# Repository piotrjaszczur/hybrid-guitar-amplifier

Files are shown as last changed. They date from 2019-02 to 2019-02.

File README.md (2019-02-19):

# hybrid-guitar-amplifier
Hybrid guitar amplifier project for the Design Laboratory course at AGH

This amplifier consists of valve preamplifier and solid state power amplifier.

Equalizer
The schematic for the equalizer was taken from the AVT186 kit. The values of the components were changed to provide three bands for the filters: 100Hz, 800Hz and 6400Hz.

eq board

eq schematic

MOSFET overdive effect
It was simple two stage amplifier to create distorted signal with a harsh clipping.

mos board

mos schematic

Channel select board
This board allowed to change the channels of the preamplifier and control the effects loop with 3 analog multiplexers. They were handled by the Atmega328p microcontroller. 

mux board

mux schematic

Power amplifier
The TDA7292 was used in the bridge tied load configuration to increase the power output in this stage.

poweramp board

poweramp schematic

Valve preamplifier
This circuit was based around 12AX7 valve. The double triode provided two gain stages in order to achieve overdriven signal.

preamp board

preamp schematic

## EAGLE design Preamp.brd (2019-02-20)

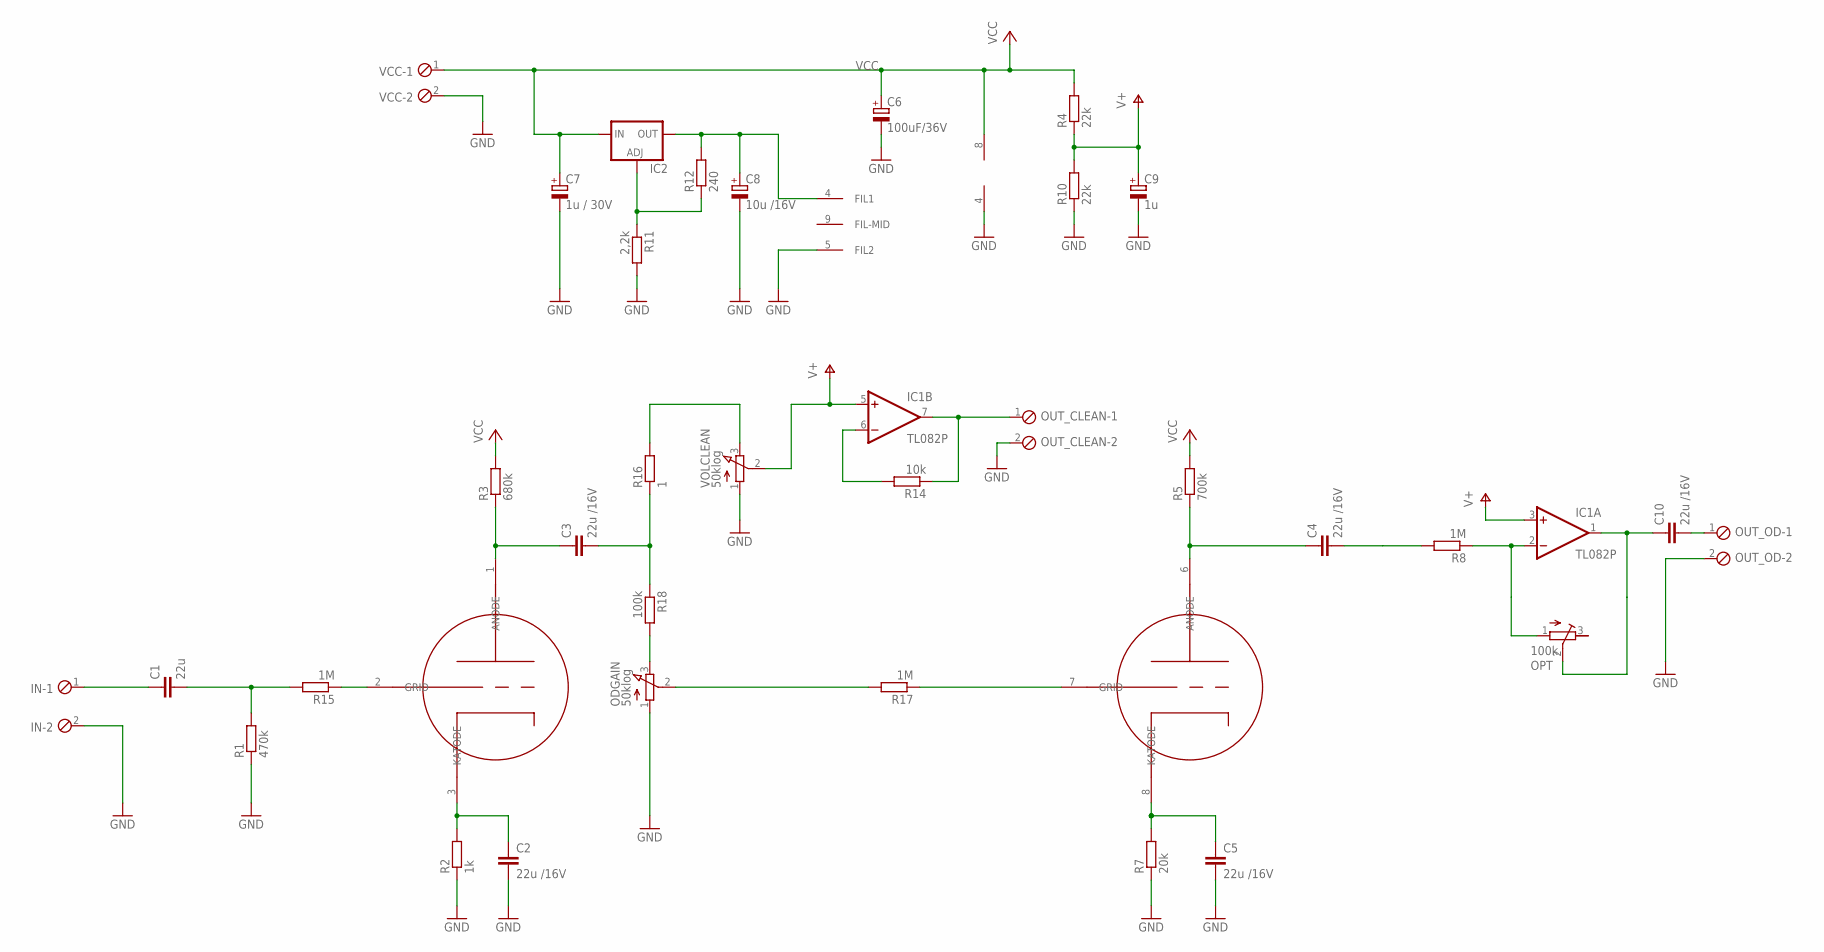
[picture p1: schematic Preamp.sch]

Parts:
C1: 22u; C050-030X075
C2, C3, C4, C5, C10: 22u /16V; C050-030X075
C6: 100uF/36V; E2,5-5
C7: 1u / 30V; E2,5-5
C8: 10u /16V; E2,5-5
C9: 1u; E2,5-5
IC1: TL082P; DIL08
IC2: LM317TS; 317TS
IN: MPT2; 2POL254
ODGAIN: 50klog; 3RP/1610N
OPT: 100k; RTRIM74W
OUT_CLEAN: MPT2; 2POL254
OUT_OD: MPT2; 2POL254
R1: 470k; 0207/12
R2: 1k; 0207/12
R3: 680k; 0207/12
R4, R10: 22k; 0207/12
R5: 700k; 0207/12
R7: 20k; 0207/10
R8, R15, R17: 1M; 0207/12
R11: 2,2k; 0207/12
R12: 240; 0207/12
R14: 10k; 0204/7
R16: 1; 0207/12
R18: 100k; 0207/12
U$1: 12AX7
VCC: MPT2; 2POL254
VOLCLEAN: 50klog; 3RP/1610N

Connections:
GND: C2.2, C5.2, C6.-, C7.-, C8.-, C9.-, IC1.4 (V-), IN.2, ODGAIN.1 (A), OUT_CLEAN.2, OUT_OD.2, R1.1, R2.1, R7.1, R10.1, R11.2, U$1.5 (FIL2), VCC.2, VOLCLEAN.1 (A)
unnamed: C1.2, R1.2, R15.2
unnamed: C2.1, R2.2, U$1.3 (KATODE)
unnamed: C5.1, R7.2, U$1.8 (KATODE)
unnamed: C3.1, R3.1, U$1.1 (ANODE)
unnamed: C3.2, R16.1, R18.1
unnamed: C4.1, R5.1, U$1.6 (ANODE)
unnamed: C4.2, R8.2
unnamed: C1.1, IN.1
unnamed: IC1.2 (-IN), OPT.1 (A), R8.1
unnamed: ODGAIN.2 (S), R17.2
unnamed: C10.1, IC1.1 (OUT), OPT.2 (S)
unnamed: IC1.7 (OUT), OUT_CLEAN.1, R14.1
unnamed: C8.+, IC2.2 (OUT), R12.2, U$1.4 (FIL1)
unnamed: R15.1, U$1.2 (GRID)
unnamed: IC2.1 (ADJ), R11.1, R12.1
unnamed: IC1.6 (-IN), R14.2
unnamed: R17.1, U$1.7 (GRID)
unnamed: R16.2, VOLCLEAN.3 (E)
unnamed: ODGAIN.3 (E), R18.2
unnamed: C10.2, OUT_OD.1
V+: C9.+, IC1.3 (+IN), IC1.5 (+IN), R4.1, R10.2, VOLCLEAN.2 (S)
VCC: C6.+, C7.+, IC1.8 (V+), IC2.3 (IN), R3.2, R4.2, R5.2, VCC.1

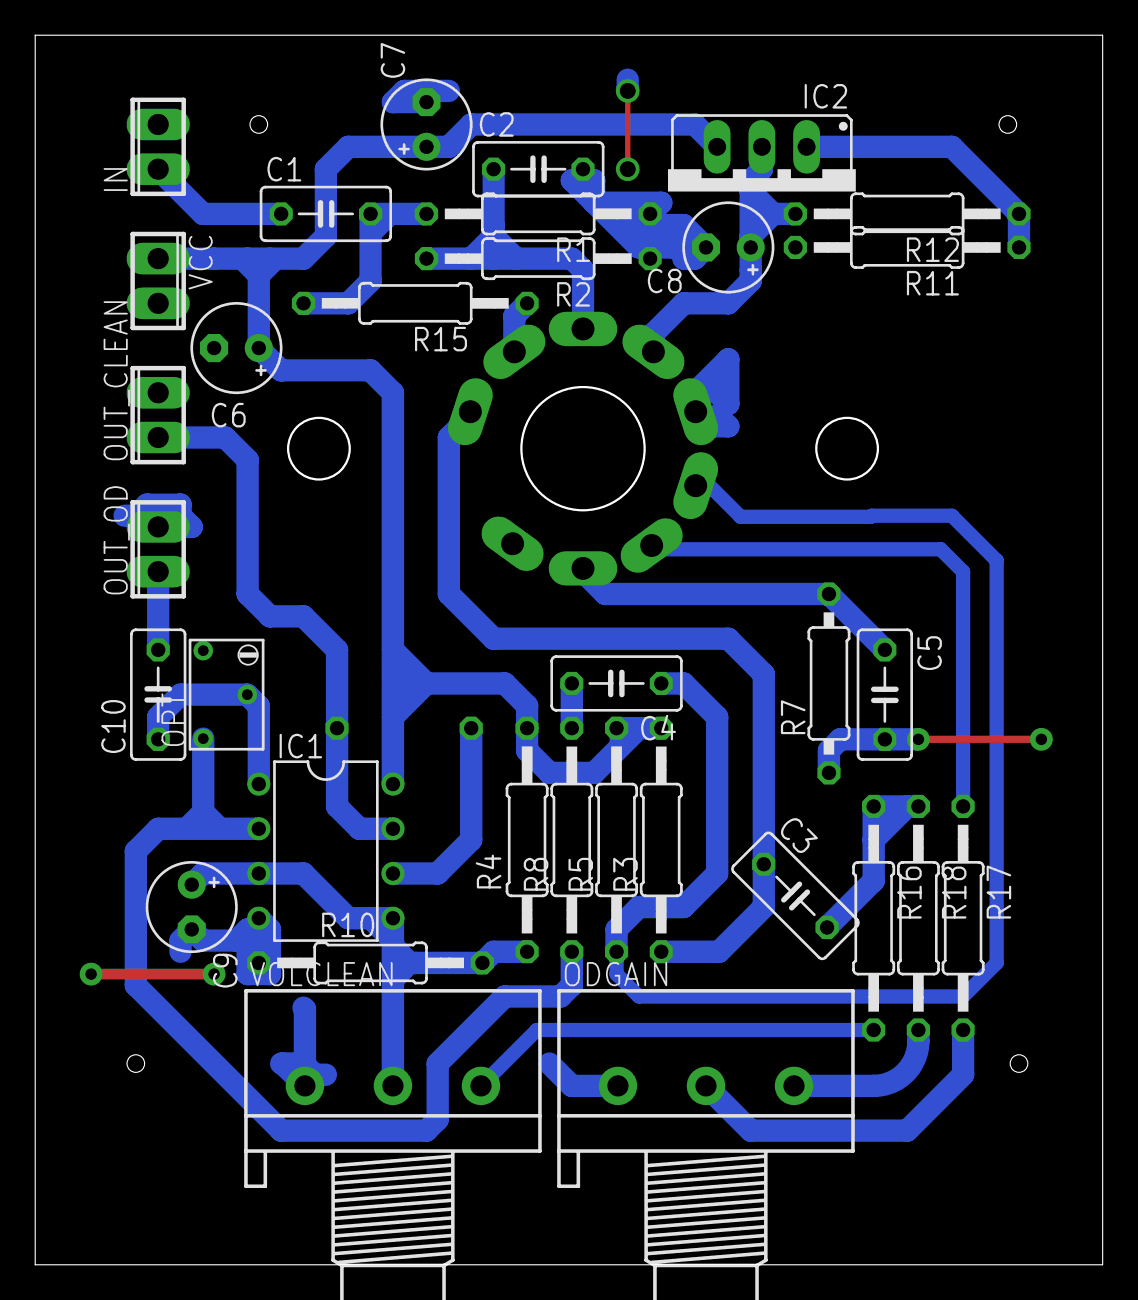
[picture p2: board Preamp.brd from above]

Board: 2 copper layers, 60.6 x 69.8 mm, 35 parts (1 on the bottom side), 23 nets.

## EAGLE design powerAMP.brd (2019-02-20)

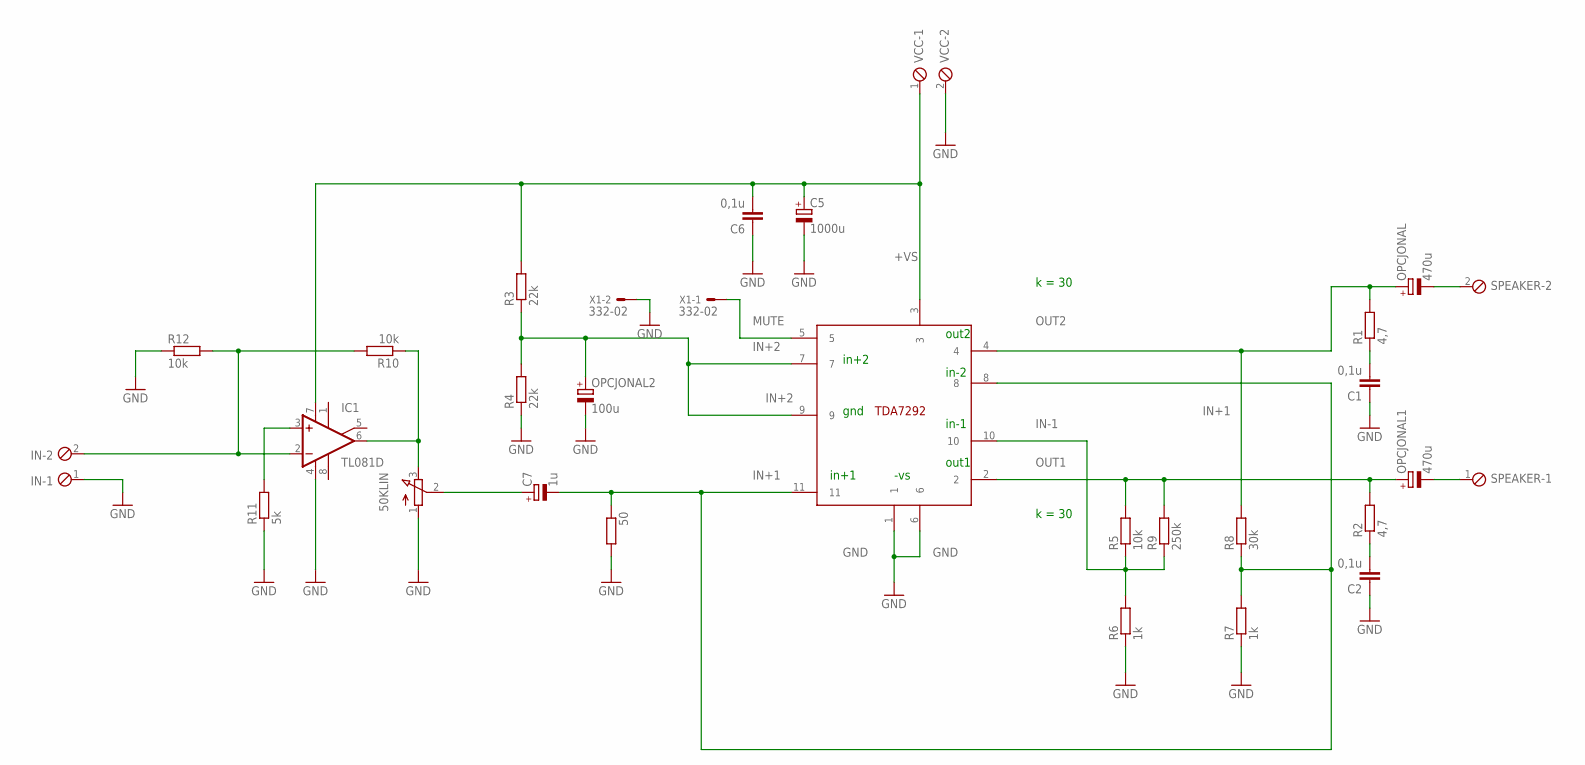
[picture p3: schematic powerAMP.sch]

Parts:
50: R-EU_M0805; M0805
50KLIN: 3RP/1610N
C1, C2, C6: 0,1u; C1206
C5: 1000u; E2,5-7
C7: 1u; E2,5-5
IC1: TL081D; SO08
IN: MPT2; 2POL254
OPCJONAL, OPCJONAL1: 470u; E2,5-7
OPCJONAL2: 100u; E2,5-7
R1, R2: 4,7; M0805
R3, R4: 22k; M0805
R5, R10, R12: 10k; M0805
R6, R7: 1k; M0805
R8: 30k; M0805
R9: 250k; M0805
R11: 5k; M0805
SPEAKER: MPT2; 2POL254
U$1: TDA7292TDA7292; MULTIWATT11
VCC: MPT2; 2POL254
X1: 332-02

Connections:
+VS: C5.+, C6.2, IC1.7 (V+), R3.2, U$1.3, VCC.1
GND: 50.2, 50KLIN.1 (A), C1.1, C2.1, C5.-, C6.1, IC1.4 (V-), IN.1, OPCJONAL2.-, R4.1, R6.1, R7.1, R11.1, R12.1, U$1.1, U$1.6, VCC.2, X1.2
IN+1: 50.1, C7.-, R7.2, R8.1, U$1.8, U$1.11
IN+2: OPCJONAL2.+, R3.1, R4.2, U$1.7, U$1.9
IN-1: R5.1, R6.2, R9.1, U$1.10
MUTE: U$1.5, X1.1
unnamed: C1.2, R1.1
unnamed: 50KLIN.3 (E), IC1.6 (OUT), R10.1
unnamed: 50KLIN.2 (S), C7.+
unnamed: C2.2, R2.1
unnamed: IC1.2 (-IN), IN.2, R10.2, R12.2
unnamed: IC1.3 (+IN), R11.2
OUT1: OPCJONAL1.+, R2.2, R5.2, R9.2, U$1.2
OUT2: OPCJONAL.+, R1.2, R8.2, U$1.4
SPK+: OPCJONAL1.-, SPEAKER.1
SPK-: OPCJONAL.-, SPEAKER.2

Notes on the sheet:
in-1
in+2
in-2
in+1
gnd
-vs
out1
out2
k = 30

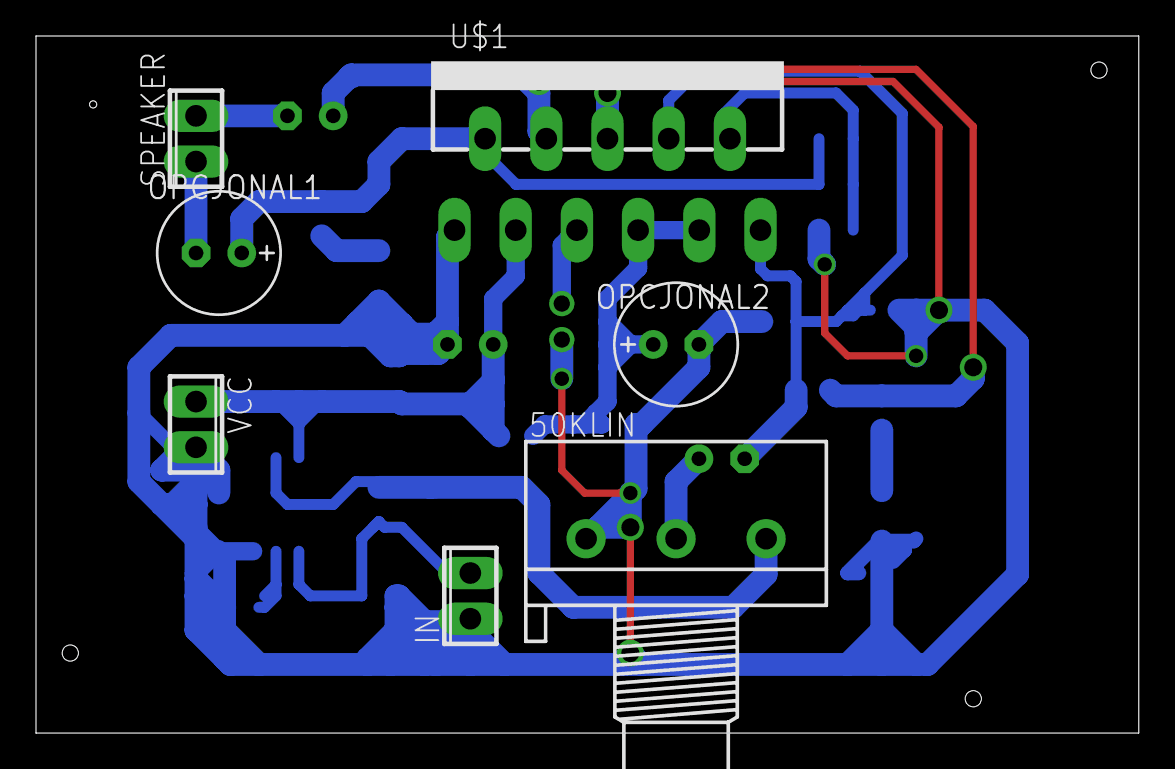
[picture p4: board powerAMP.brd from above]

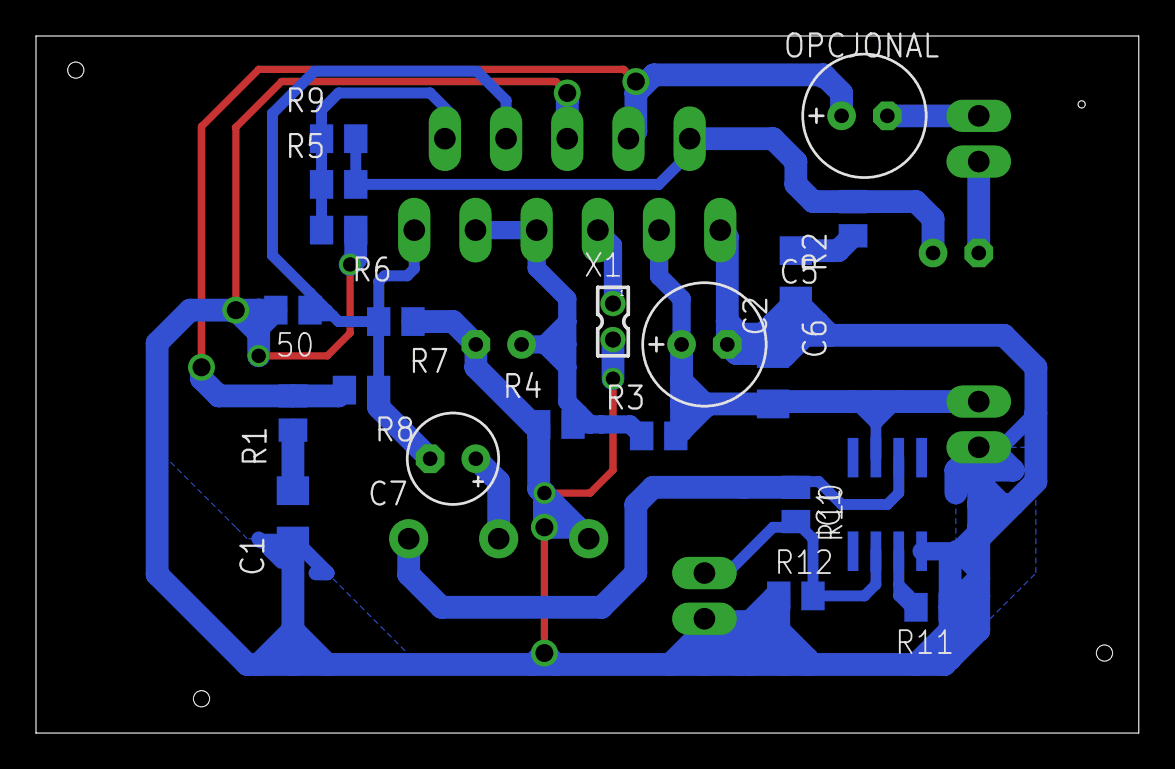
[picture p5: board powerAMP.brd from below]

Board: 2 copper layers, 61.3 x 38.7 mm, 28 parts (21 on the bottom side), 16 nets.

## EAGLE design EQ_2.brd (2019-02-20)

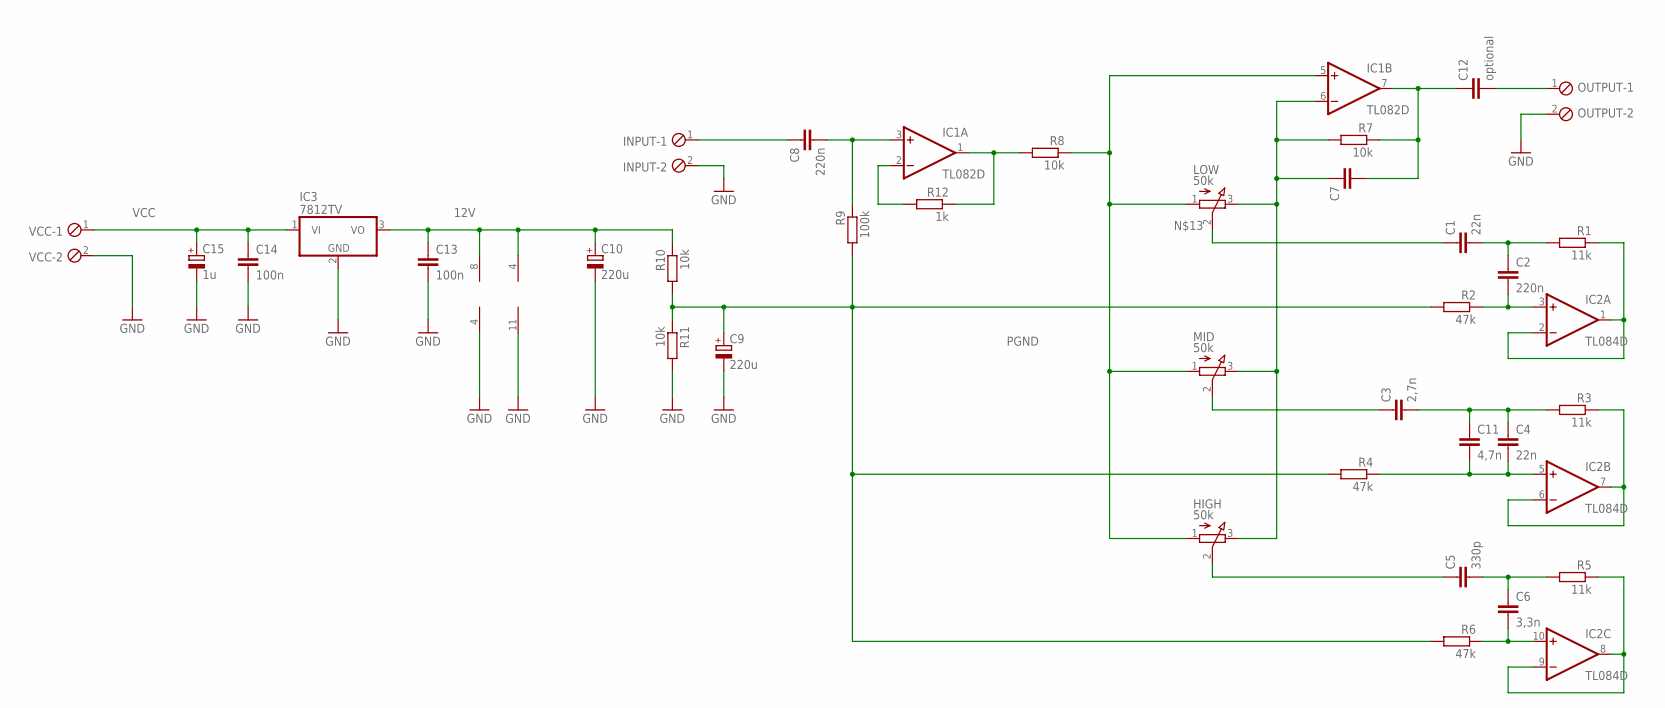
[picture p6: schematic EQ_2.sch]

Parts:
C1, C4: 22n; C1206
C2, C8: 220n; C1206
C3: 2,7n; C1206
C5: 330p; C1206
C6: 3,3n; C1206
C7: C-EUC1206; C1206
C9, C10: 220u; E2,5-5
C11: 4,7n; C1206
C12: optional; C1206
C13, C14: 100n; C1206
C15: 1u; E2,5-5
HIGH: 50k; 3RP/1610N
IC1: TL082D; SO08
IC2: TL084D; SO14
IC3: 7812TV; TO220V
INPUT: MPT2; 2POL254
LOW: 50k; 3RP/1610N
MID: 50k; 3RP/1610N
OUTPUT: MPT2; 2POL254
R1, R3, R5: 11k; R0805
R2, R4, R6: 47k; R0805
R7, R8, R10, R11: 10k; R0805
R9: 100k; R0805
R12: 1k; R0805
VCC: MPT2; 2POL254

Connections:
12V: C10.+, C13.1, IC1.8 (V+), IC2.4 (V+), IC3.3 (VO), R10.1
GND: C9.-, C10.-, C13.2, C14.2, C15.-, IC1.4 (V-), IC2.11 (V-), IC3.2 (GND), INPUT.2, OUTPUT.2, R11.2, VCC.2
unnamed: C2.2, IC2.3 (+IN), R2.1
unnamed: C1.2, C2.1, R1.2
unnamed: IC2.1 (OUT), IC2.2 (-IN), R1.1
unnamed: C3.2, C4.1, C11.1, R3.2
unnamed: C4.2, C11.2, IC2.5 (+IN), R4.1
unnamed: IC2.6 (-IN), IC2.7 (OUT), R3.1
unnamed: C5.2, C6.1, R5.2
unnamed: C6.2, IC2.10 (+IN), R6.1
unnamed: IC2.8 (OUT), IC2.9 (-IN), R5.1
unnamed: C7.2, C12.1, IC1.7 (OUT), R7.1
unnamed: C8.2, IC1.3 (+IN), R9.1
unnamed: C7.1, HIGH.3 (E), IC1.6 (-IN), LOW.3 (E), MID.3 (E), R7.2
unnamed: HIGH.1 (A), IC1.5 (+IN), LOW.1 (A), MID.1 (A), R8.1
unnamed: IC1.1 (OUT), R8.2, R12.1
unnamed: IC1.2 (-IN), R12.2
unnamed: C8.1, INPUT.1
unnamed: C5.1, HIGH.2 (S)
unnamed: C3.1, MID.2 (S)
unnamed: C1.1, LOW.2 (S)
unnamed: C12.2, OUTPUT.1
PGND: C9.+, R2.2, R4.2, R6.2, R9.2, R10.2, R11.1
VCC: C14.1, C15.+, IC3.1 (VI), VCC.1

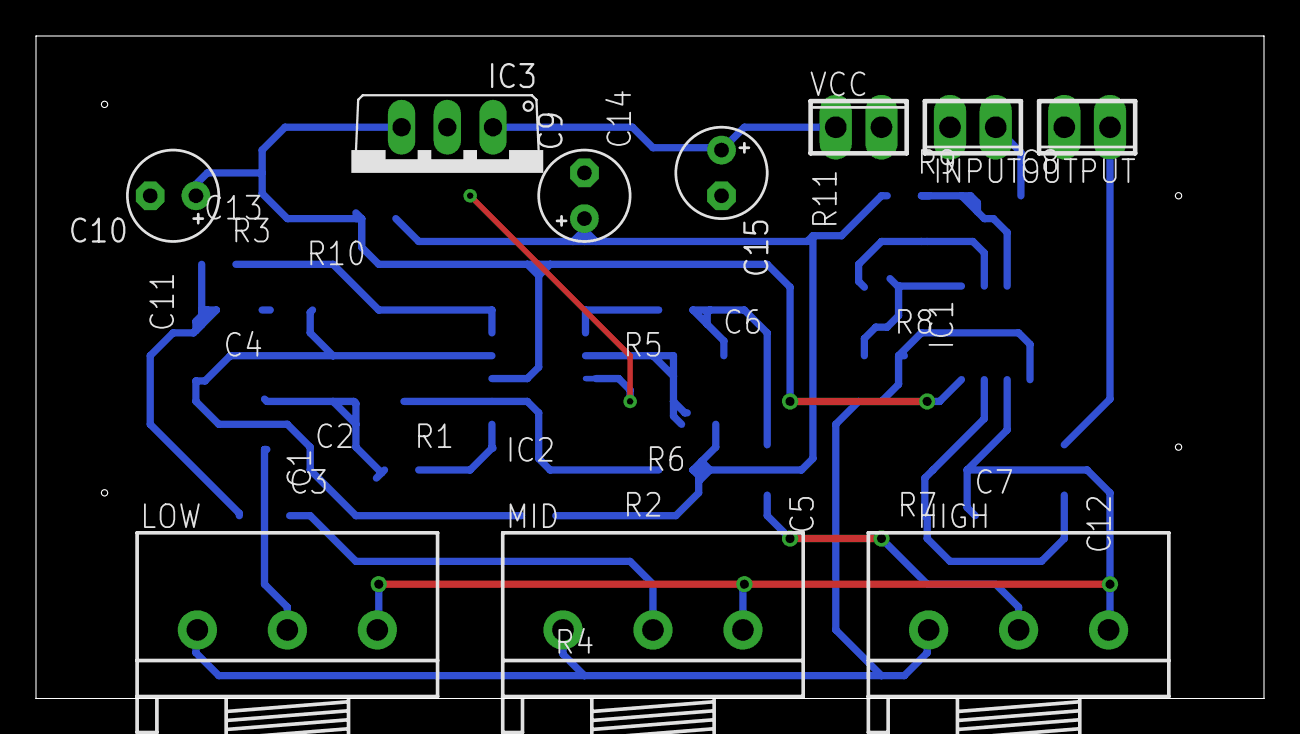
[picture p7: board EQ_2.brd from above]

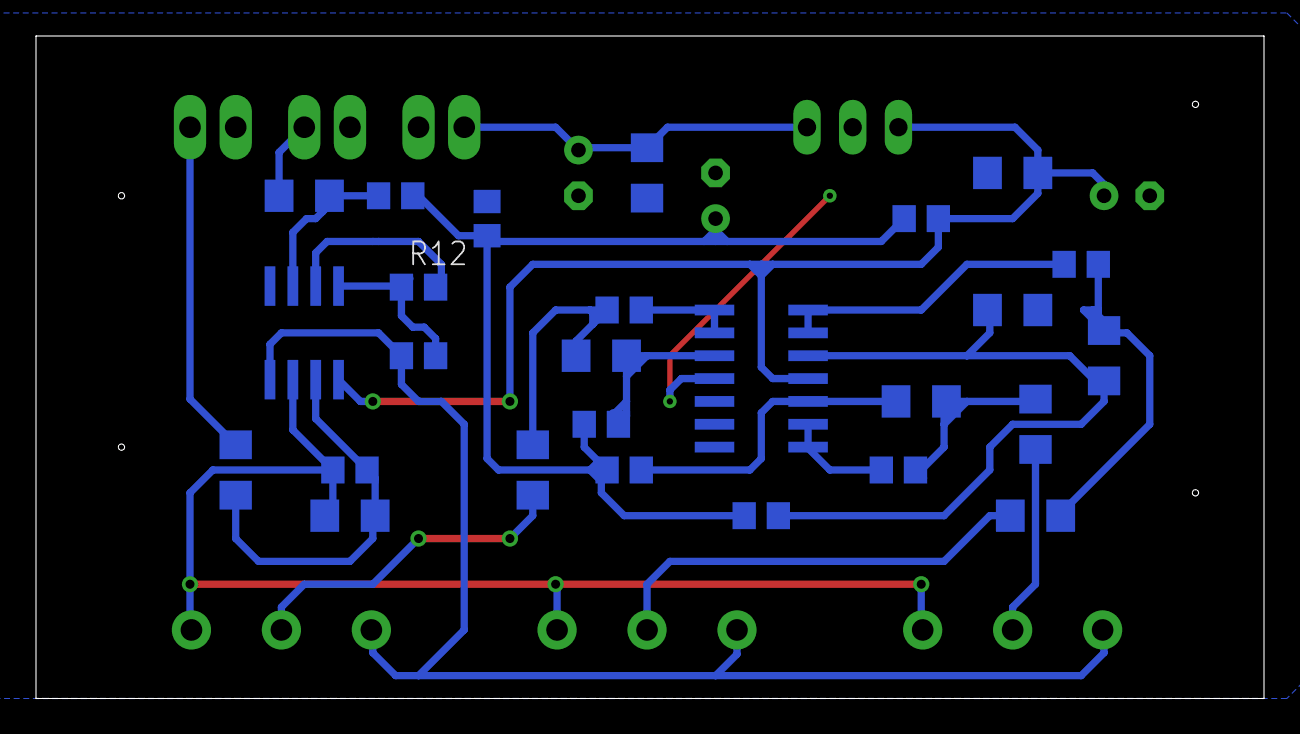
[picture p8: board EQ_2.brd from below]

Board: 2 copper layers, 68.2 x 36.8 mm, 36 parts (26 on the bottom side), 24 nets.

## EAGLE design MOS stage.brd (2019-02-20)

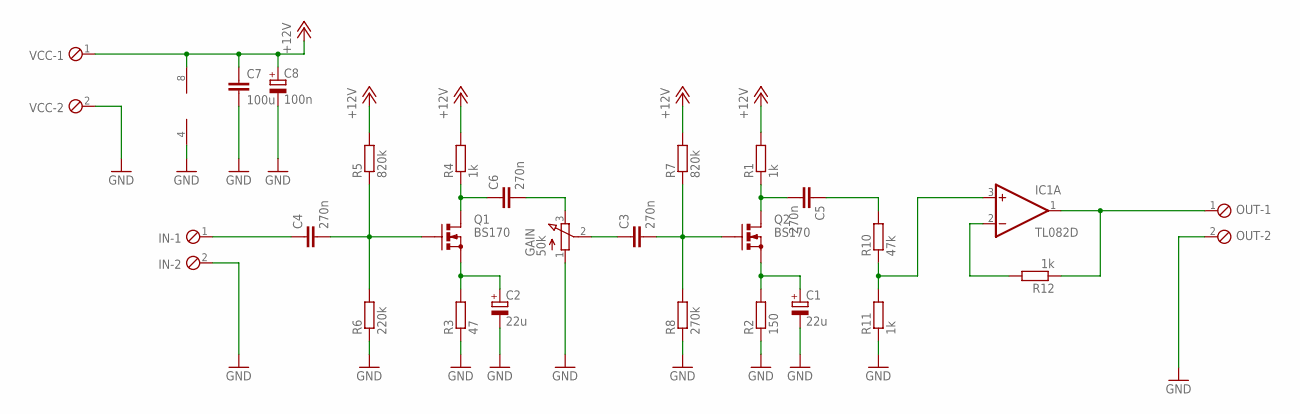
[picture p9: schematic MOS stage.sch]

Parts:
C1, C2: 22u; E2,5-5
C3, C4, C5, C6: 270n; C1206
C7: 100u; C1206
C8: 100n; E2,5-5
GAIN: 50k; 3RP/1610N
IC1: TL082D; SO08
IN: MPT2; 2POL254
OUT: MPT2; 2POL254
Q1, Q2: BS170; SOT54E
R1, R4, R11, R12: 1k; R0805
R2: 150; R0805
R3: 47; R0805
R5, R7: 820k; R0805
R6: 220k; R0805
R8: 270k; R0805
R10: 47k; R0805
VCC: MPT2; 2POL254

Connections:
+12V: C7.1, C8.+, IC1.8 (V+), R1.2, R4.2, R5.2, R7.2, VCC.1
GND: C1.-, C2.-, C7.2, C8.-, GAIN.1 (A), IC1.4 (V-), IN.2, OUT.2, R2.1, R3.1, R6.1, R8.1, R11.1, VCC.2
unnamed: C5.2, Q2.D, R1.1
unnamed: C3.2, Q2.G, R7.1, R8.2
unnamed: C1.+, Q2.S, R2.2
unnamed: C6.1, Q1.D, R4.1
unnamed: C2.+, Q1.S, R3.2
unnamed: C4.2, Q1.G, R5.1, R6.2
unnamed: C4.1, IN.1
unnamed: C5.1, R10.2
unnamed: C6.2, GAIN.3 (E)
unnamed: C3.1, GAIN.2 (S)
unnamed: IC1.3 (+IN), R10.1, R11.2
unnamed: IC1.1 (OUT), OUT.1, R12.1
unnamed: IC1.2 (-IN), R12.2

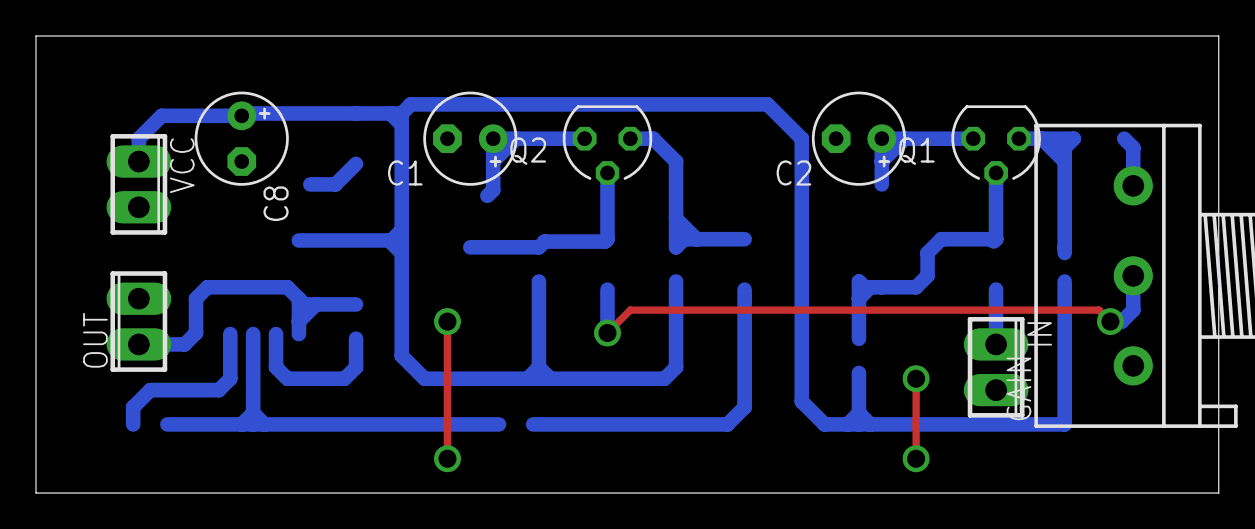
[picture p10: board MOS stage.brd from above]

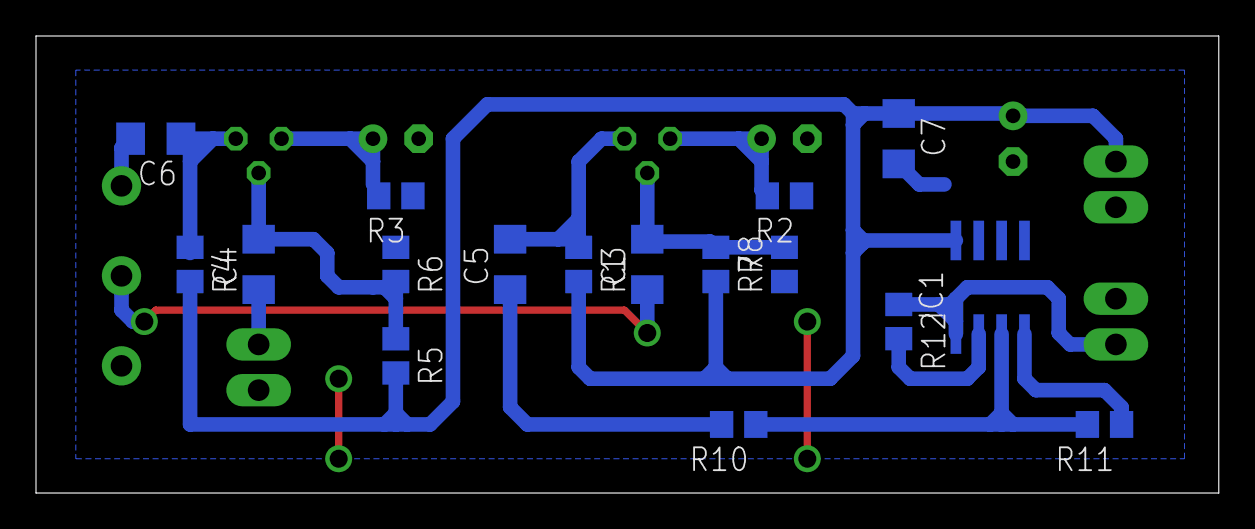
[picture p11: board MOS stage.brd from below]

Board: 2 copper layers, 65.7 x 25.4 mm, 26 parts (17 on the bottom side), 15 nets.

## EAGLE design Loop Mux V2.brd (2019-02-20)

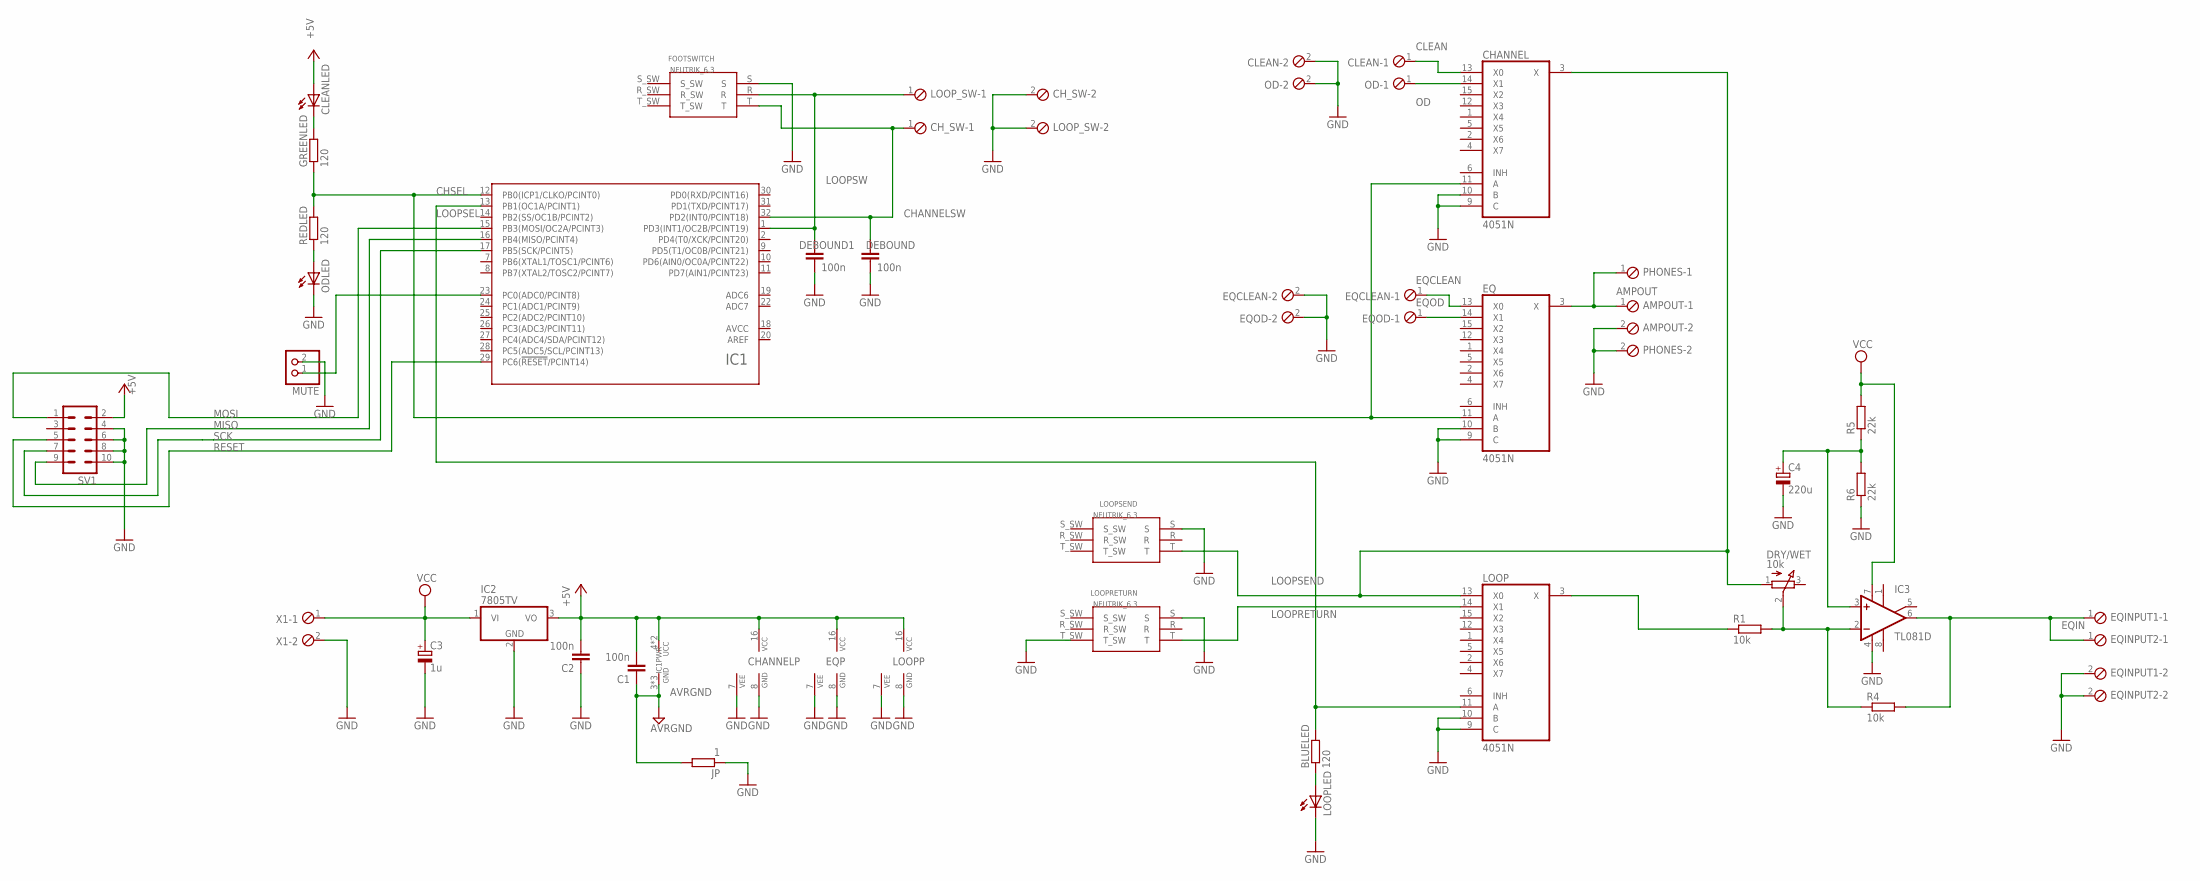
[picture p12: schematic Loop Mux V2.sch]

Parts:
AMPOUT: MPT2; 2POL254
BLUELED: 120; R0805
C1, C2: 100n; C1206
C3: 1u; E2-5
C4: 220u; E2,5-5
CHANNEL: 4051N; DIL16
CH_SW: MPT2; 2POL254
CLEAN: MPT2; 2POL254
CLEANLED: LED5MM
DEBOUND, DEBOUND1: 100n; C1206
DRY/WET: 10k; 3RP/1610N
EQ: 4051N; DIL16
EQCLEAN: MPT2; 2POL254
EQINPUT1, EQINPUT2: MPT2; 2POL254
EQOD: MPT2; 2POL254
FOOTSWITCH: NEUTRIK_6.3
GREENLED: 120; R0805
IC1: ATMEGA48/88/168/328-AU; TQFP32-08
IC2: 7805TV; TO220V
IC3: TL081D; SO08
JP: 1; R0805
LOOP: 4051N; DIL16
LOOPLED: LED5MM
LOOPRETURN: NEUTRIK_6.3
LOOPSEND: NEUTRIK_6.3
LOOP_SW: MPT2; 2POL254
MUTE: PINHD-1X2; 1X02
OD: MPT2; 2POL254
ODLED: LED5MM
PHONES: MPT2; 2POL254
R1, R4: 10k; R0805
R5, R6: 22k; R0805
REDLED: 120; R0805
SV1: MA05-2
X1: MPT2; 2POL254

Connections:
+5V: C1.2, C2.2, CHANNEL.16 (VCC), CLEANLED.A, EQ.16 (VCC), IC1.4 (UCC), IC1.6 (UCC), IC2.3 (VO), LOOP.16 (VCC), SV1.2
AMPOUT: AMPOUT.1, EQ.3 (X), PHONES.1
AVCC: IC1.18 (AVCC)
AVRGND: C1.1, IC1.3 (GND), IC1.5 (GND), IC1.21 (GND), JP.2
CHANNELSW: CH_SW.1, DEBOUND.1, FOOTSWITCH.T, IC1.32 (PD2(INT0/PCINT18))
CHSEL: CHANNEL.11 (A), EQ.11 (A), GREENLED.1, IC1.12 (PB0(ICP1/CLKO/PCINT0)), REDLED.2
CLEAN: CHANNEL.13 (X0), CLEAN.1
EQCLEAN: EQ.13 (X0), EQCLEAN.1
EQIN: EQINPUT1.1, EQINPUT2.1, IC3.6 (OUT), R4.2
EQOD: EQ.14 (X1), EQOD.1
GND: AMPOUT.2, C2.1, C3.-, C4.-, CHANNEL.7 (VEE), CHANNEL.8 (GND), CHANNEL.9 (C), CHANNEL.10 (B), CH_SW.2, CLEAN.2, DEBOUND.2, DEBOUND1.2, EQ.7 (VEE), EQ.8 (GND), EQ.9 (C), EQ.10 (B), EQCLEAN.2, EQINPUT1.2, EQINPUT2.2, EQOD.2, FOOTSWITCH.S, IC2.2 (GND), IC3.4 (V-), JP.1, LOOP.7 (VEE), LOOP.8 (GND), LOOP.9 (C), LOOP.10 (B), LOOPLED.K (C), LOOPRETURN.S, LOOPRETURN.T_SW, LOOPSEND.S, LOOP_SW.2, MUTE.2, OD.2, ODLED.K (C), PHONES.2, R6.1, SV1.4, SV1.6, SV1.8, SV1.10, X1.2
LOOPRETURN: LOOP.14 (X1), LOOPRETURN.T
LOOPSEL: BLUELED.2, IC1.13 (PB1(OC1A/PCINT1)), LOOP.11 (A)
LOOPSEND: CHANNEL.3 (X), DRY/WET.1 (A), LOOP.13 (X0), LOOPSEND.T
LOOPSW: DEBOUND1.1, FOOTSWITCH.R, IC1.1 (PD3(INT1/OC2B/PCINT19)), LOOP_SW.1
MISO: IC1.16 (PB4(MISO/PCINT4)), SV1.9
MOSI: IC1.15 (PB3(MOSI/OC2A/PCINT3)), SV1.1
unnamed: ODLED.A, REDLED.1
unnamed: IC1.23 (PC0(ADC0/PCINT8)), MUTE.1
unnamed: CLEANLED.K (C), GREENLED.2
unnamed: LOOP.3 (X), R1.1
unnamed: DRY/WET.2 (S), IC3.2 (-IN), R1.2, R4.1
unnamed: BLUELED.1, LOOPLED.A
unnamed: C4.+, IC3.3 (+IN), R5.1, R6.2
OD: CHANNEL.14 (X1), OD.1
RESET: IC1.29 (PC6(!RESET!/PCINT14)), SV1.5
SCK: IC1.17 (PB5(SCK/PCINT5)), SV1.7
VCC: C3.+, IC2.1 (VI), IC3.7 (V+), R5.2, X1.1



Board: 2 copper layers, 100.0 x 80.0 mm, 40 parts (15 on the bottom side), 27 nets.
